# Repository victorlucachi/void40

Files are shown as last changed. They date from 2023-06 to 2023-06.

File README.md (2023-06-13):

# VOID40
*A 40% handwired ortholinear keyboard*

VOID40

The VOID40 is a 3d printed, handwired, 40% ortholinear keyboard running QMK Firmware on a Pro Micro controller. The case is designed to fit the bed of a stock Ender 3 when the parts are rotated 45 degrees and the skirt/brim is disabled in the slicers settings.

I suggest printing the case using a 0.4 mm nozzle, supports are not needed for any of the parts.

You might want/need to use small dabs of hot glue to secure the switches in the plate depending on how well calibrated your printer is (if you're generous with it, it will add to the weight of the keyboard and it might change the feel of it).

Dont overtighten the screws as the posts could break off and the threads might get stripped.

# Handwiring guide

I've also put together a pretty visual handwiring guide for the VOID9, that you can browse over [here](https://victorlucachi.ro/journal/void9-wiring-guide/).

|  	|  	|  	|
|---|---|---|

# Bill Of Materials

* 48 x diodes ([tme.eu](https://www.tme.eu/ro/en/details/1n4148-dio/tht-universal-diodes/diotec-semiconductor/1n4148/)/[aliexpress](https://www.aliexpress.com/item/32729204179.html))
* 48 x Cherry MX style mechanical switches
* 48 x keycaps of choice
* 1 x Pro Micro ([aliexpress](https://www.aliexpress.com/item/32902569443.html))
* 1 x EC11 Rotary Encoder ([aliexpress](https://www.aliexpress.com/item/32872039030.html)/mounted to the plate using [this adapter](https://www.thingiverse.com/thing:3770166))
* 24 AWG (0.2 mm2) wire
* 4 x 8mm bumpons

### Redux
* 10 x M2x3x3.5 OD heat inserts ([aliexpress](https://www.aliexpress.com/item/4000585933306.html?spm=a2g0o.order_list.order_list_main.33.21ef1802vdSNrS))
* 4 x M2x10 Allen head screws ([aliexpress](https://www.aliexpress.com/item/32966941844.html?spm=a2g0o.order_detail.order_detail_item.9.722ff19cyjrixq))
* 6 x M2x6 Countersunk screws ([aliexpress](https://www.aliexpress.com/item/32968097507.html?spm=a2g0o.order_list.order_list_main.32.21ef1802vdSNrS))

### V1
* 4 x M3x10 countersunk screws that go through the top case ([tme.eu](https://www.tme.eu/ro/en/details/b3x10_bn661/bolts/bossard/1250752/)/[aliexpress](https://www.aliexpress.com/item/32968097507.html))
* 4 x M3x10 allen head screws ([tme.eu](https://www.tme.eu/ro/en/details/m3x10_d912-a2/bolts/kraftberg/)/[aliexpress](https://www.aliexpress.com/item/32966941844.html))
* hotglue

# Pin assignment

    ROW0    ROW1    ROW2    ROW3
    D3      D2      D1      D0

    COL0    COL1    COL2    COL3    COL4    COL5    COL6    COL7    COL8    COL9    COL10   COL11
    D4      C6      D7      E6      B4      B5      F4      F5      F6      F7      B1      B3

    Encoder Pad A           Encoder Pad B
    B6                      B2

# QMK Vial Fork

A QMK Vial fork can be found [here](https://github.com/victorlucachi/vial-qmk/tree/dev_void/keyboards/handwired/void40).

Most features are disabled in order for the firmware to fit on the atmega32u4 present on the Pro Micro controllers, but if you want to tinker around with different features or if you're using a different MCU you can enable/disable them to suit your own needs by editing the rules.mk file in the vial keymap folder.

The web version of Vial is available at [vial.rocks](https://vial.rocks/); it runs in supported browsers (Chrome, Edge and Opera) without requiring an installation.

VOID40 Vial

# QMK Fork

A fork containing the QMK config files can be found [here](https://github.com/victorlucachi/qmk_firmware/tree/dev_void/keyboards/handwired/void40). Edit them to suit your own needs and build the firmware following the QMK docs.

If you plan on using the VIA configurator dont forget to download the json definitions file linked in this repository.



This work is licensed under a [Creative Commons Attribution-NonCommercial-ShareAlike 4.0 International License](https://creativecommons.org/licenses/by-nc-sa/4.0/).

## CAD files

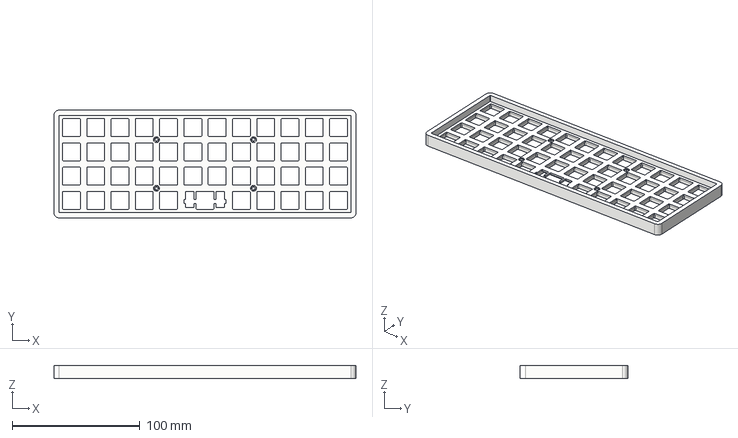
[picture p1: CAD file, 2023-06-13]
Redux/STEP/VOID40 Redux - Top - MIT.step
236.8 x 84.4 x 10.0 mm

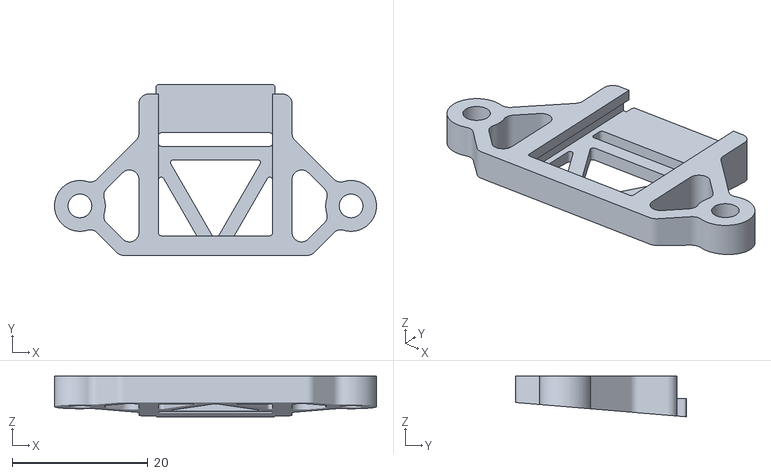
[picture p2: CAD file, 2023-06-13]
Redux/STL/Controller/21.5x18mm - Seeed Xiao - Angled.stl
47.5 x 25.2 x 6.00

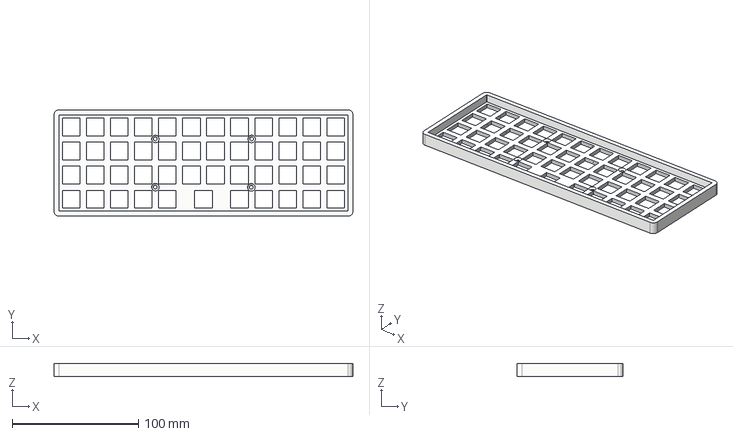
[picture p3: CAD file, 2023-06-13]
v1/STEP/VOID40OP - Top MIT.step
236.7 x 84.3 x 10.0 mm

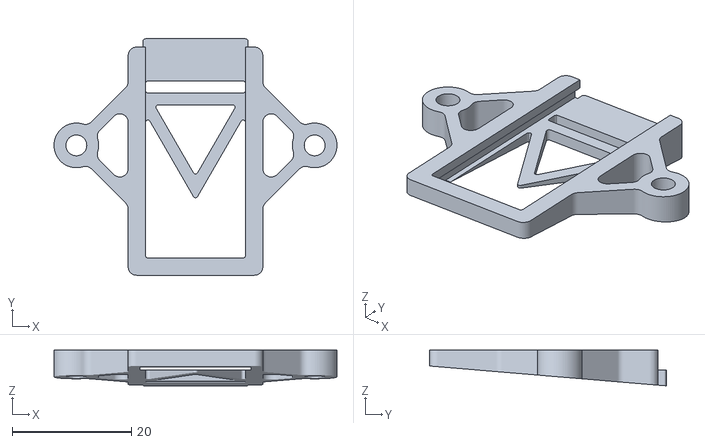
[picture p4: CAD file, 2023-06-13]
Redux/STL/Controller/36x18mm - Type C Pro Micro - Angled.stl
47.5 x 39.7 x 6.00

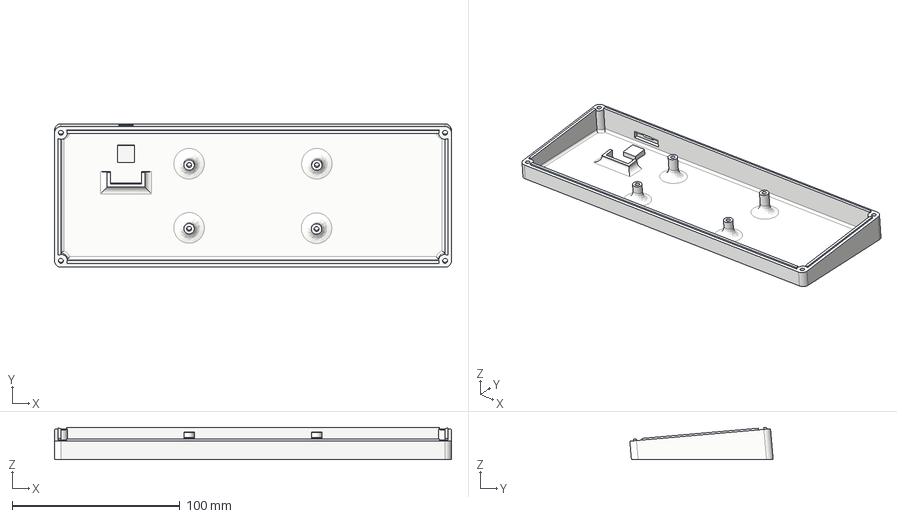
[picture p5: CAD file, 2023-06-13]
v1/STEP/VOID40OP - Bottom.step
236.7 x 85.6 x 19.1 mm

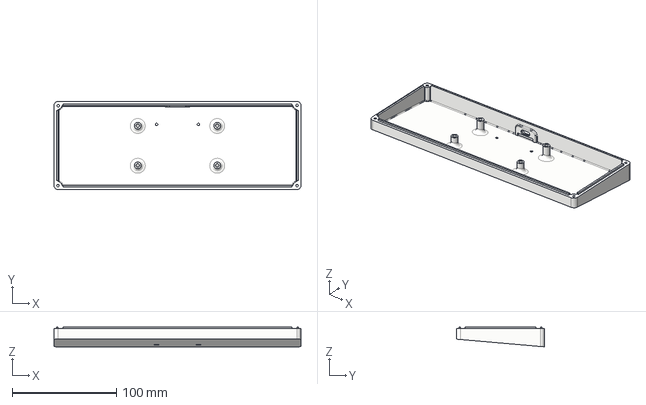
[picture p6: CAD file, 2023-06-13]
Redux/STEP/VOID40 Redux - Bottom - Angled.step
236.9 x 84.4 x 18.9 mm

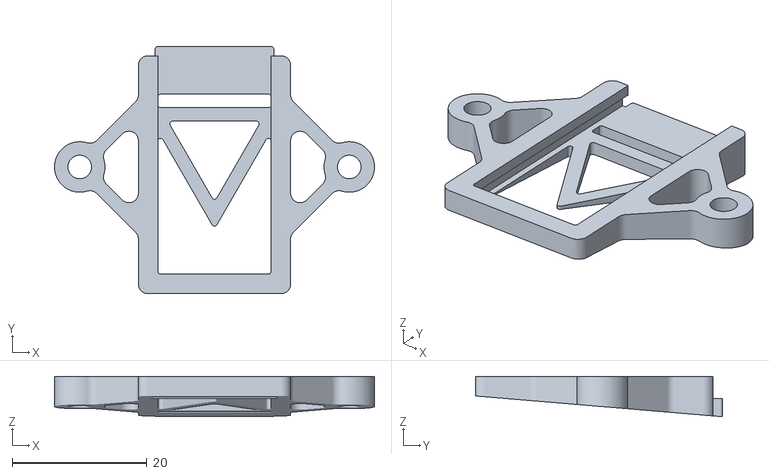
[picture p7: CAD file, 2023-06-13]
Redux/STL/Controller/33x18mm - Pro Micro - Angled.stl
47.5 x 36.7 x 6.00

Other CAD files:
Redux/STEP/VOID40 Redux - Top - Grid.step
v1/STEP/VOID40OP - Top GRID.step
Redux/STL/VOID40 Redux - Bottom - Angled.stl
Redux/STL/VOID40 Redux - Top - Grid.stl
Redux/STL/VOID40 Redux - Top - MIT.stl
v1/STL/VOID40OP - Bottom.stl
v1/STL/VOID40OP - Top GRID.stl
v1/STL/VOID40OP - Top MIT.stl

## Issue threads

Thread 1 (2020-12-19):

REQUEST: not angled and tinner bottom design

Giorgiofox, 2020-12-19:
Hello,
is possible to ask for a not angled and thinner bottom design?
I'm very curious to test a more flat design, also for more portability.
thank in advance

victorlucachi, 2020-12-19:
Hey Giorgio,

The current design is 11mm in height at the slimmest point (first row). Image attached below for further explanation.

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

I went through a couple of iterations for the VOID40 before settling on the design that is currently uploaded to Thingiverse and Github, here are some of my considerations:

A flat design would negatively impact the space that is available on the inside of the keyboard; handwired builds vary from one person to another, the diameter of the wiring can be thicker or thinner, as well as tidier or messier, and we also need to keep in mind that the controller requires a little bit of breathing room around it for everything to come together.

Based on the above, what in theory could be a slimmer keyboard/case might actually end up as a pile of plastic that cant be assembled properly or with ease by everyone that decides on printing it.

In conclusion, I would have to say that at least for the moment I'm not interested in making another version that is flat, but you're more than welcome to replicate my design or straight up modify it (my projects are licensed under Creative Commons - Attribution - Non Commercial).

Giorgiofox, 2020-12-20:
Thank you very much for your complete and kind reply. You are right, looking at the section image. Thanks again and many thanks for this project

YassineGherbi, 2022-05-22:
If you're still looking for a design like the one you mentioned, someone on Thingiverse made something that might suit your needs. https://www.thingiverse.com/thing:5202886

Giorgiofox, 2022-10-11:
Thank you very much !
Kind regards
Giorgio

Il giorno dom 22 mag 2022 alle 09:21 Yassine Gherbi <
***@***.***> ha scritto:

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
--
Giorgio
***@***.***
Secure: ***@***.***

Closed 2020-12-19.

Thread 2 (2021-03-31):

step files?

hanhanhan-kim, 2021-03-31:
Hello!
Thanks for building and designing such a great 40% keyboard! I'm really enjoying it! (and am using it right now!)
I was wondering if it might be possible to ask for the solid CAD files, e.g. in `.step` format, as opposed to the mesh `.stl` files. I was thinking it might be fun to modify the design a bit so it can accept an alternative microcontroller :)
Thanks so much!

victorlucachi, 2021-04-01:
Hey,

Thank you for the kind words. I've just added the `.step` files to the repository.

Closed 2021-04-01.

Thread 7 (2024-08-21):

Does not fit Ender3

Lucky4Luuk, 2024-08-21:
According to the description, it's meant to fit the Ender3 print area. But once the STL has been imported into Cura, the actual model is 236.85mm wide!

victorlucachi, 2024-08-21:
_... when the parts are rotated 45 degrees and the skirt/brim is disabled in the slicers settings._

Lucky4Luuk, 2024-08-21:
Oh that makes a lot of sense, awesome, thank you!

tommyblue, 2024-09-12:
@victorlucachi I'm trying to print it in an Ender 3 V3 KE, but it doesn't fit (220x220x240). Is it supposed to work on such printer?
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

victorlucachi, 2024-09-12:
> @victorlucachi I'm trying to print it in an Ender 3 V3 KE, but it doesn't fit (220x220x240). Is it supposed to work on such printer? ![image](https://private-user-images.githubusercontent.com/122749/366864746-7fd70b10-0540-4eda-97d1-033f787c216a.png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)

I have no first hand experience with that particular model, but from what I can tell it has the same 235x235mm bed; if your toolhead and nozzle can reach all four physical corners of the bed without colliding with the frame, then I would assume that it's just a matter of firmware/slicer settings.

In the screenshot that you posted there does seem to be a ~5mm keep out zone around the perimeter of the bed, if you can remove it the model should definitely fit.

tommyblue, 2024-09-12:
oh no, it's a 220x220 bed 😢

victorlucachi, 2024-09-12:
they're kind of lying in that regard, because the physical dimension of the build plate is 235x235mm, but you have to update your firmware and slicer settings to make use of its full size.

this is the default orca slicer profile for your printer, with the bed dimensions updated to 235x235
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

tommyblue, 2024-09-12:
oh, nice, I didn't know that. I'll give it a try, thanks!

tommyblue, 2024-09-13:
Just to give you a feedback, with the Ender3 V3KE I tried enlarging the plate size to 230x230, the slicer (Prusa) is then able to fit the object and send the gcode but the printer stops when it should reach the plate limit, with a message about the coordinates being out of the printable area

victorlucachi, 2024-09-13:
yes, that makes sense. as previously stated, you also have to adjust the bed size in your firmware.

I don't know if newer versions of the ender still run marlin firmware, but if the answer is yes, you have to adjust bed size in the firmware config, recompile and reflash your motherboard.

tommyblue, 2024-09-13:
oh thanks for the hint, let's see if I can brick my printer 😅

victorlucachi, 2024-09-13:
> oh thanks for the hint, let's see if I can brick my printer 😅

I think [this](https://github.com/Guilouz/Creality-Helper-Script-Wiki) _might_ be the answer, but definitely do a bit of research on the matter. good luck!🤞

Closed 2024-08-21.

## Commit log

2021-04-01 Added .step files
    [VOID40OP - Bottom.step, VOID40OP - Top GRID.step, VOID40OP - Top MIT.step]
2022-10-28 updated via definitions file to include encoder
2023-06-13 redux prep
    - restructured repo
    - added precompiled fw
    - prep for redux models
    [VOID40OP - Bottom.step, VOID40OP - Bottom.stl, VOID40OP - Top GRID.step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]
2023-06-13 VOID40 Redux
    - added redux models
    - modular pro micro controller mount
    - m2 hardware
    - m2 brass inserts
    [VOID40 Redux - Bottom - Angled.step, VOID40 Redux - Bottom - Angled.stl, VOID40 Redux - Pro Micro - Angled.step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]
2023-06-13 properly export step files
    [VOID40 Redux - Bottom - Angled.step, VOID40 Redux - Pro Micro - Angled.step, VOID40 Redux - Top - Grid.step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]
2023-06-13 modular controller mounts
    - added modular mounts for a couple of controllers
    [21.5x18mm - Seeed Xiao - Angled.stl, 23.5x18mm - Waveshare rp2040 zero - Angled.stl, 33x18mm - Pro Micro - Angled.stl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]
2023-07-03 removed waveshare controller mount
    [23.5x18mm - Waveshare rp2040 zero - Angled.stl]

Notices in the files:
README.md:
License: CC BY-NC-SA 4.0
